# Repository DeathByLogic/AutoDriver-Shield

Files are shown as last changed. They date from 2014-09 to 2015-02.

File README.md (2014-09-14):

AutoDriver SPI over RS-485 Shield
=================

Shield for the Sparkfun AutoDriver stepper motor driver to communicate with SPI over RS-485. This allows for communications to and from the AutoDriver over long distances. The companion to this board is the Arduino SPI over RS-485 Shield.

https://www.sparkfun.com/products/11611

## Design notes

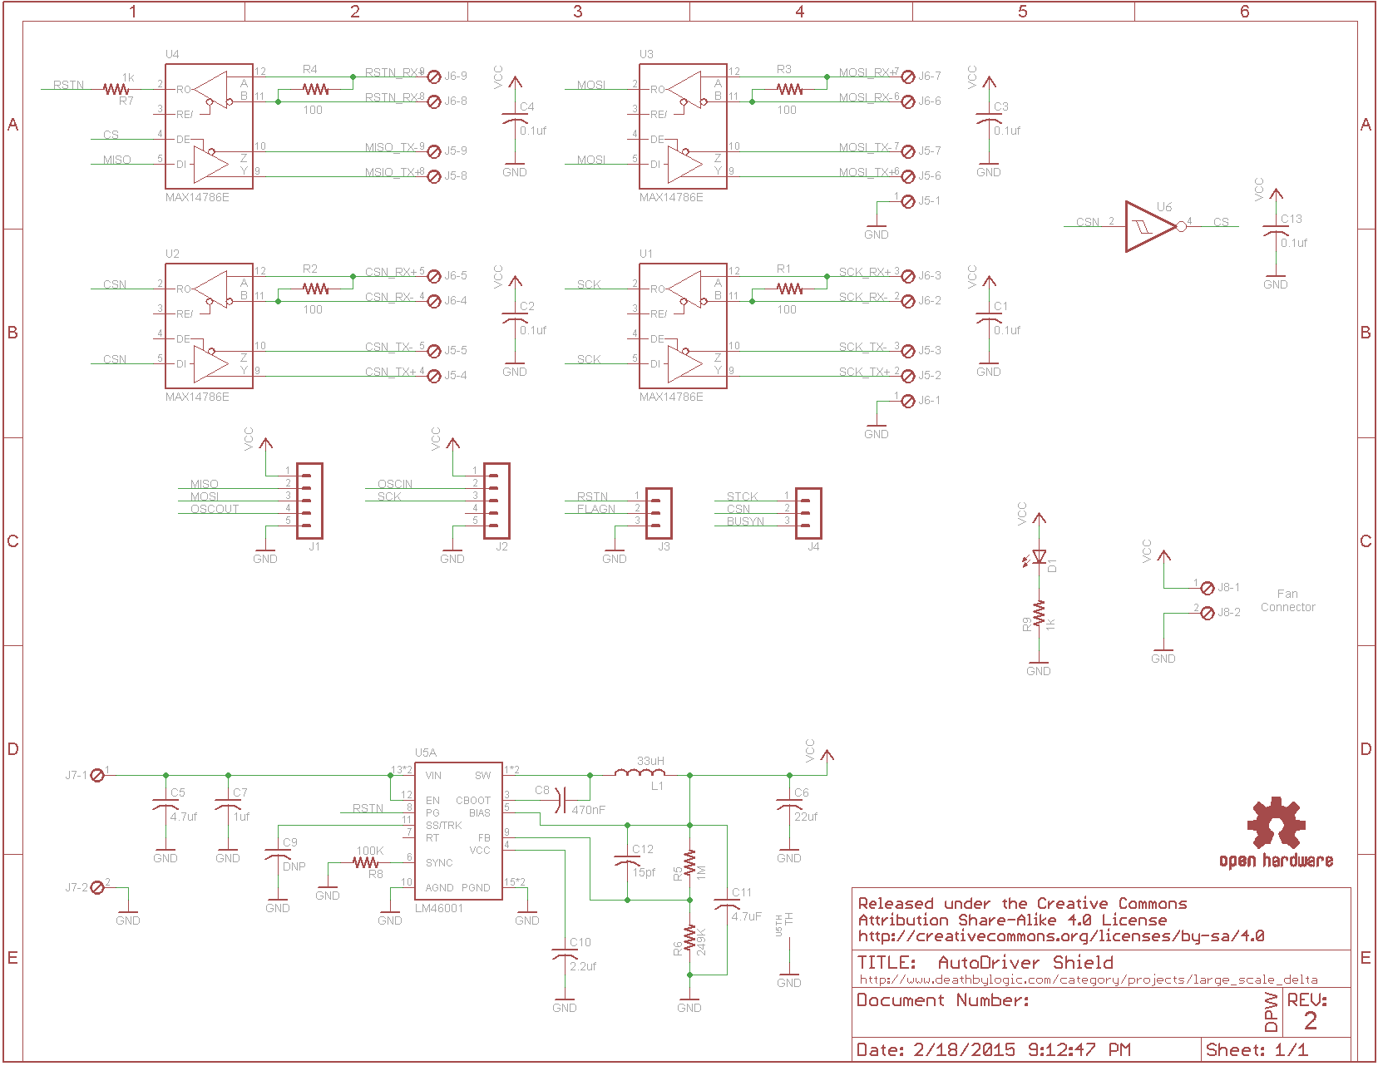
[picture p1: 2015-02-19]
AutoDriver Shield Schematic.png

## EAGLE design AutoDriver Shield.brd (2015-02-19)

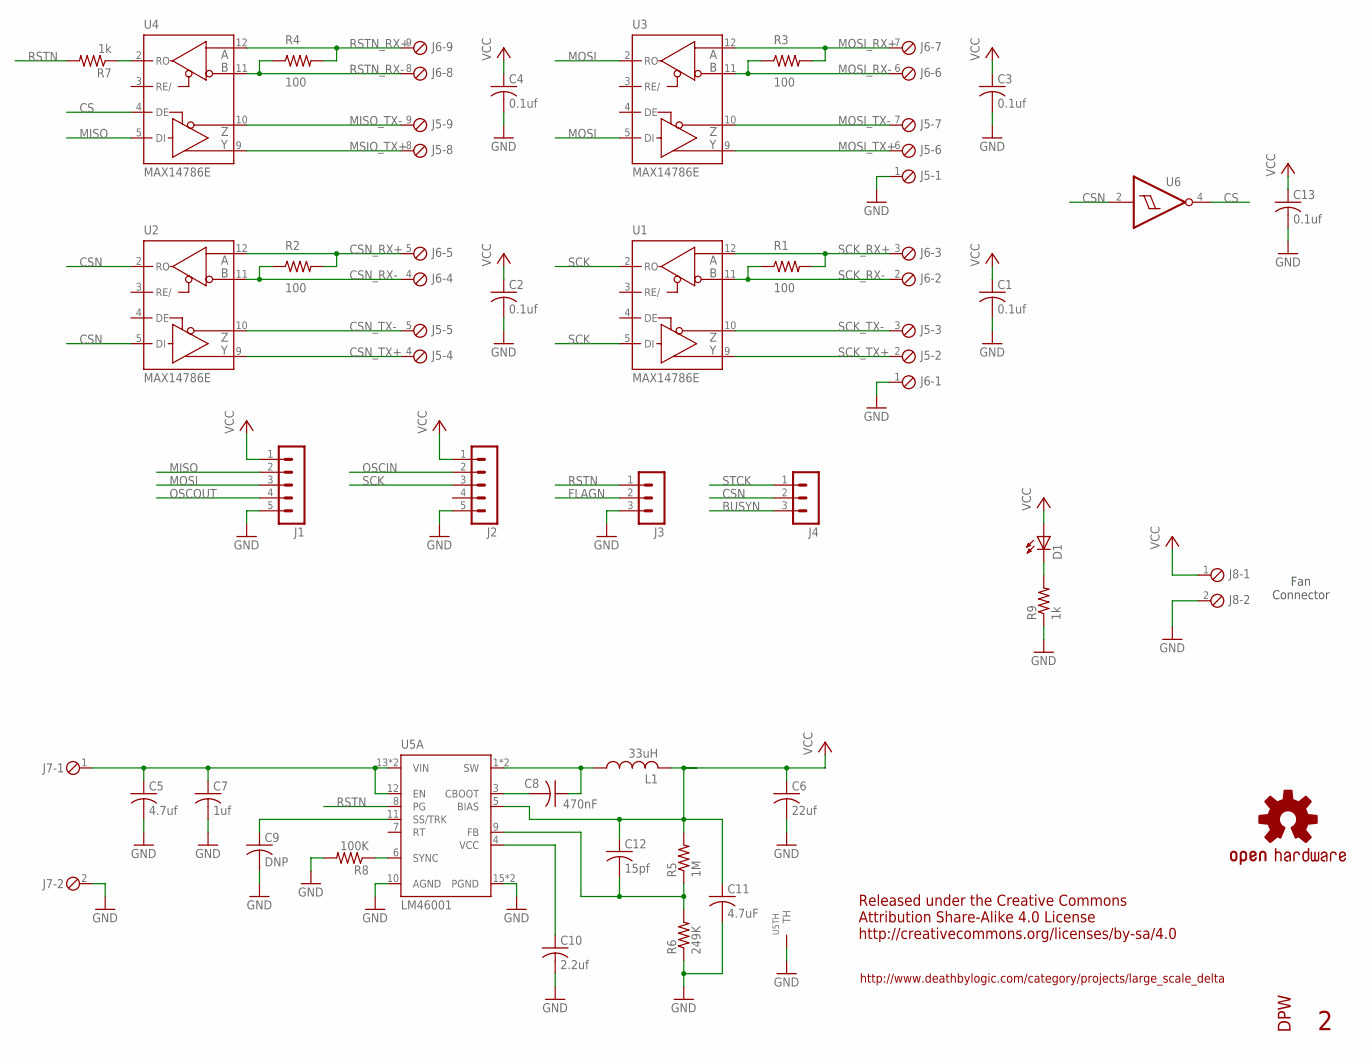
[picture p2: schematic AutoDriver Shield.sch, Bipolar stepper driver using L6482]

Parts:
C1, C2, C3, C4, C13: 0.1uf; C0805K
C5: 4.7uf; C1210K
C6: 22uf; C1210K
C7: 1uf; C1206K
C8: 470nF; C0805K
C9: DNP; C0603K
C10: 2.2uf; C0603K
C11: 4.7uF; C0805K
C12: 15pf; C0805K
D1: LEDCHIPLED_0805; CHIPLED_0805
J1, J2: MA05-1
J3, J4: MA03-1
J5, J6: MPT9; 9POL254
J7, J8: MPT2; 2POL254
L1: 33uH; L6045
LOGO1: OSHW-LOGOM; OSHW-LOGO-M
R1, R2, R3, R4: 100; R1206
R5: 1M; R0402
R6: 249K; R0402
R7, R9: 1k; R0805
R8: 100K; R0402
U1, U2, U3, U4: MAX14786E; SO14
U5: LM46001; HTSSOP16PWP
U6: 74AHC1G14; SOT23-5
U$2: PENGUIN_LOGOSILKSCREEN; PENGUIN_SILKSCREEN

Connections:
BUSYN: J4.3
CS: U4.4 (DE), U6.4 (O)
CSN: J4.2, U2.2 (RO), U2.5 (DI), U6.2 (I)
CSN_RX+: J6.5, R2.2, U2.12 (A)
CSN_RX-: J6.4, R2.1, U2.11 (B)
CSN_TX+: J5.4, U2.9 (Y)
CSN_TX-: J5.5, U2.10 (Z)
FLAGN: J3.2
GND: C1.2, C2.2, C3.2, C4.2, C5.2, C6.2, C7.2, C9.2, C10.2, C11.2, C13.2, J1.5, J2.5, J3.3, J5.1, J6.1, J7.2, J8.2, R6.1, R8.2, R9.1, U1.6 (GND), U1.7 (GND), U2.6 (GND), U2.7 (GND), U3.6 (GND), U3.7 (GND), U4.6 (GND), U4.7 (GND), U5.10 (AGND), U5.15 (PGND), U5.16 (PGND), U5.TH1 (TH), U5.TH2 (TH), U5.TH3 (TH), U5.TH4 (TH), U5.TH5 (TH), U5.TH6 (TH), U5.TH7 (TH), U5.TH8 (TH), U5.TH9 (TH), U5.TH10 (TH), U5.TH11 (TH), U5.TH12 (TH), U5.THA (TH), U5.THB (TH), U6.3 (GND)
MISO: J1.2, U4.5 (DI)
MISO_TX-: J5.9, U4.10 (Z)
MOSI: J1.3, U3.2 (RO), U3.5 (DI)
MOSI_RX+: J6.7, R3.2, U3.12 (A)
MOSI_RX-: J6.6, R3.1, U3.11 (B)
MOSI_TX+: J5.6, U3.9 (Y)
MOSI_TX-: J5.7, U3.10 (Z)
MSIO_TX+: J5.8, U4.9 (Y)
unnamed: D1.C, R9.2
unnamed: C5.1, C7.1, J7.1, U5.12 (EN), U5.13 (VIN), U5.14 (VIN)
unnamed: C9.1, U5.11 (SS/TRK)
unnamed: R8.1, U5.6 (SYNC)
unnamed: C8.1, L1.P$1 (1), U5.1 (SW), U5.2 (SW)
unnamed: C8.2, U5.3 (CBOOT)
unnamed: R7.1, U4.2 (RO)
unnamed: C10.1, U5.4 (VCC)
unnamed: C12.2, R5.1, R6.2, U5.9 (FB)
OSCIN: J2.2
OSCOUT: J1.4
RSTN: J3.1, R7.2, U5.8 (PG)
RSTN_RX+: J6.9, R4.2, U4.12 (A)
RSTN_RX-: J6.8, R4.1, U4.11 (B)
SCK: J2.3, U1.2 (RO), U1.5 (DI)
SCK_RX+: J6.3, R1.2, U1.12 (A)
SCK_RX-: J6.2, R1.1, U1.11 (B)
SCK_TX+: J5.2, U1.9 (Y)
SCK_TX-: J5.3, U1.10 (Z)
STCK: J4.1
VCC: C1.1, C2.1, C3.1, C4.1, C6.1, C11.1, C12.1, C13.1, D1.A, J1.1, J2.1, J8.1, L1.P$2 (2), R5.2, U1.14 (VCC), U2.14 (VCC), U3.14 (VCC), U4.14 (VCC), U5.5 (BIAS), U6.5 (VCC)

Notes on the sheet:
Released under the Creative Commons Attribution Share-Alike 4.0 License http://creativecommons.org/licenses/by-sa/4.0
http://www.deathbylogic.com/category/projects/large_scale_delta
Fan Connector

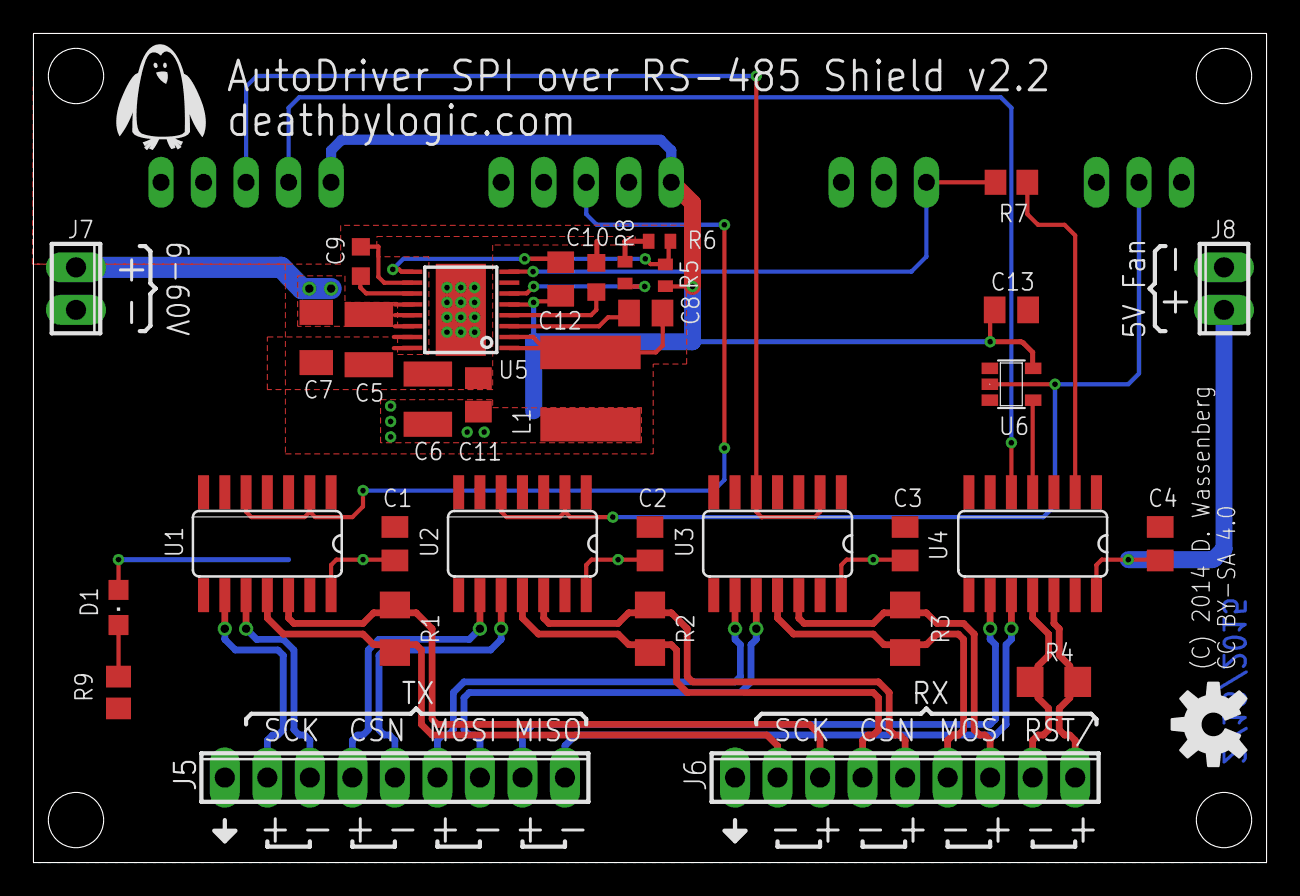
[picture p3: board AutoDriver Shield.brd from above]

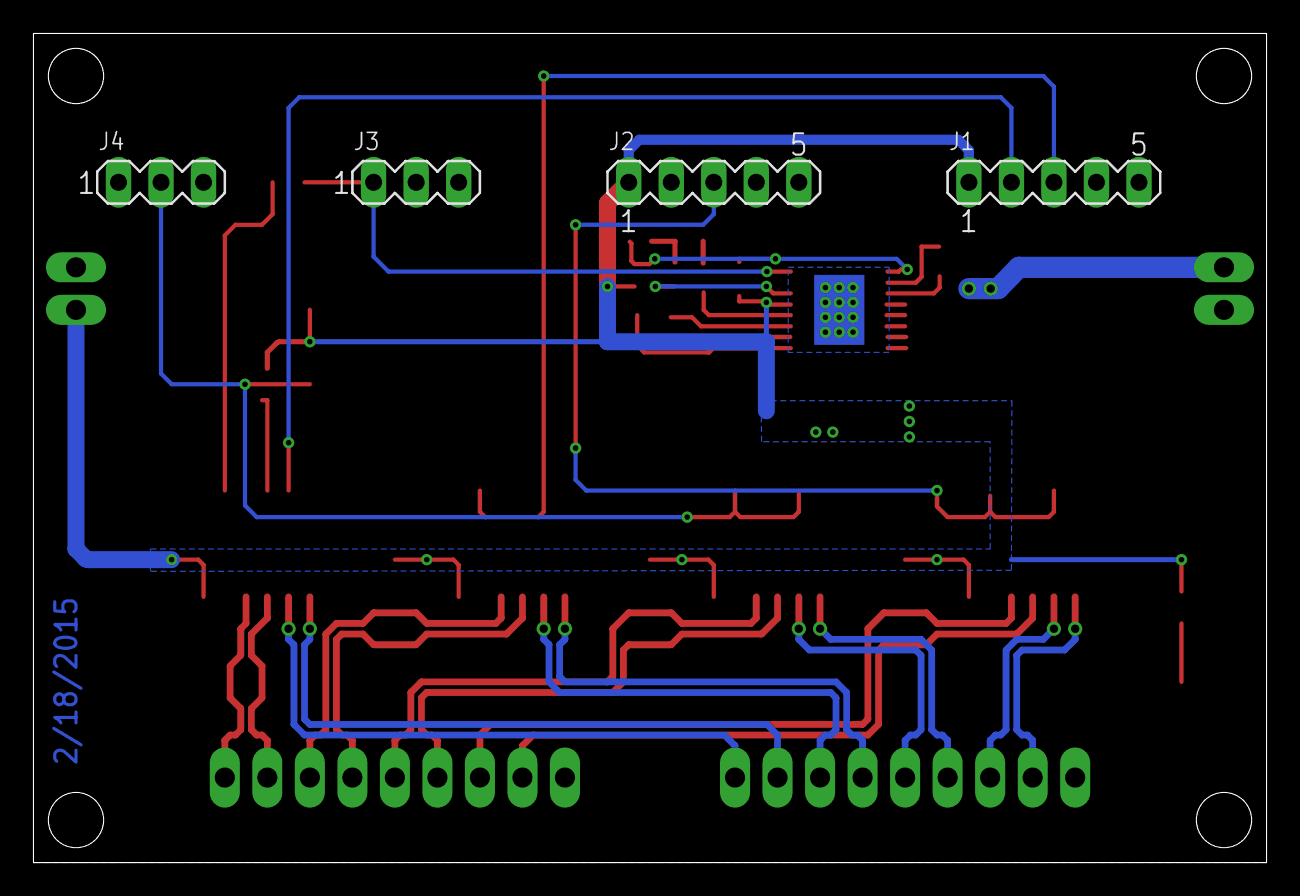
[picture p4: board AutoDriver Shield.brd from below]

Board: 2 copper layers, 73.7 x 49.5 mm, 44 parts (4 on the bottom side), 33 nets.

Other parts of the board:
STANDOFF1, STANDOFF2, STANDOFF3, STANDOFF4: STAND-OFF

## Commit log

2014-10-14 Added missing trace connecting U1 pin 2 to SCK signals.
    [AutoDriver Shield.brd]
2014-11-16 Updated gerber files to include missing trace added to board layout.
2015-02-19 Removed Non-Commercial License; Updated website address.
    [AutoDriver Shield.brd, AutoDriver Shield.sch]

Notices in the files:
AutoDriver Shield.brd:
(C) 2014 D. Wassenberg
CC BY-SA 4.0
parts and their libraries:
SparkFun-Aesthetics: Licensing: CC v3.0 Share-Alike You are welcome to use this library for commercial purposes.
